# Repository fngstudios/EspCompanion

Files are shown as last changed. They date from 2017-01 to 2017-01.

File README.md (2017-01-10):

# EspCompanion

Esp8266 + Atmega328 dev board.
Discontinued project, with Esp32 its no longer needed.

## Features  

Esp8266 and Atmega328 share the i2c bus, Esp is the master and the mega acts as a i/o
expander, with adc,pwm,serial and other libraries support.
With custom i2c library the Esp can initialize any library on the mega and it will run 
in the background untill the esp request data or sends data.

## Images

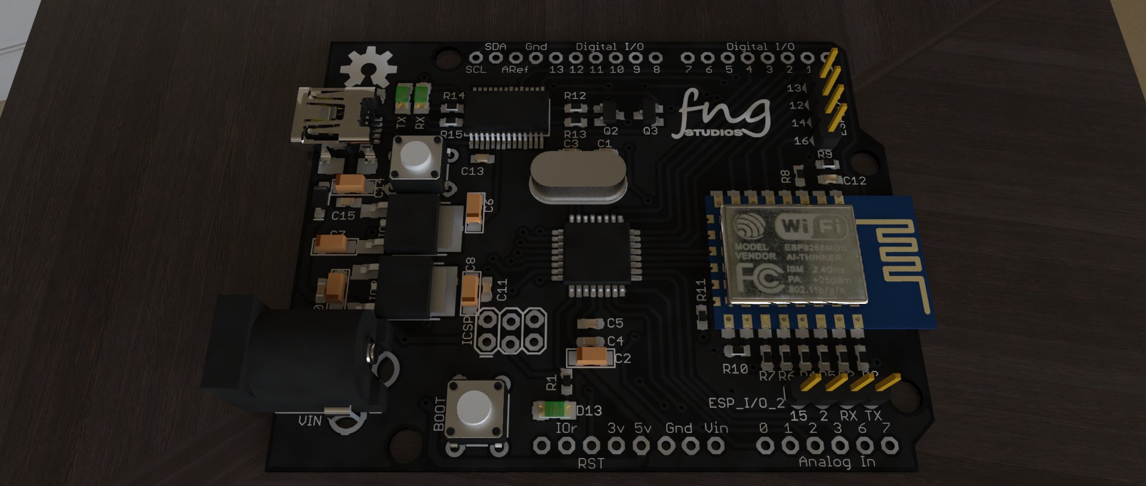
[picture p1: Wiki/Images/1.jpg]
  
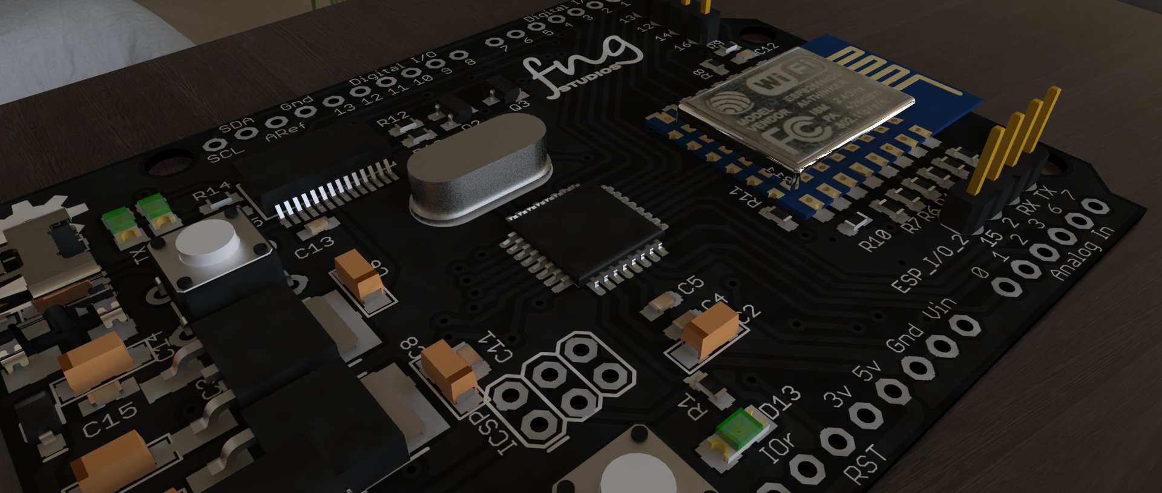
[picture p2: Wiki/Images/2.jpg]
  
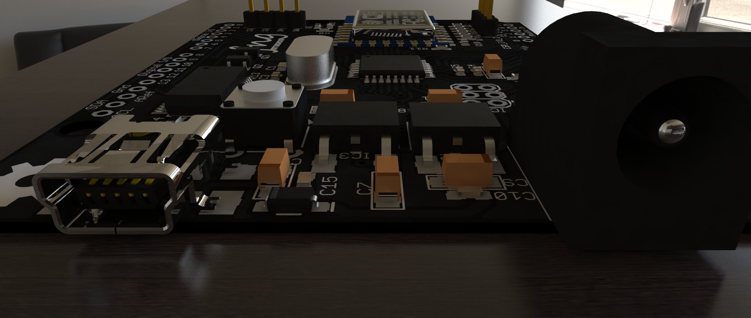
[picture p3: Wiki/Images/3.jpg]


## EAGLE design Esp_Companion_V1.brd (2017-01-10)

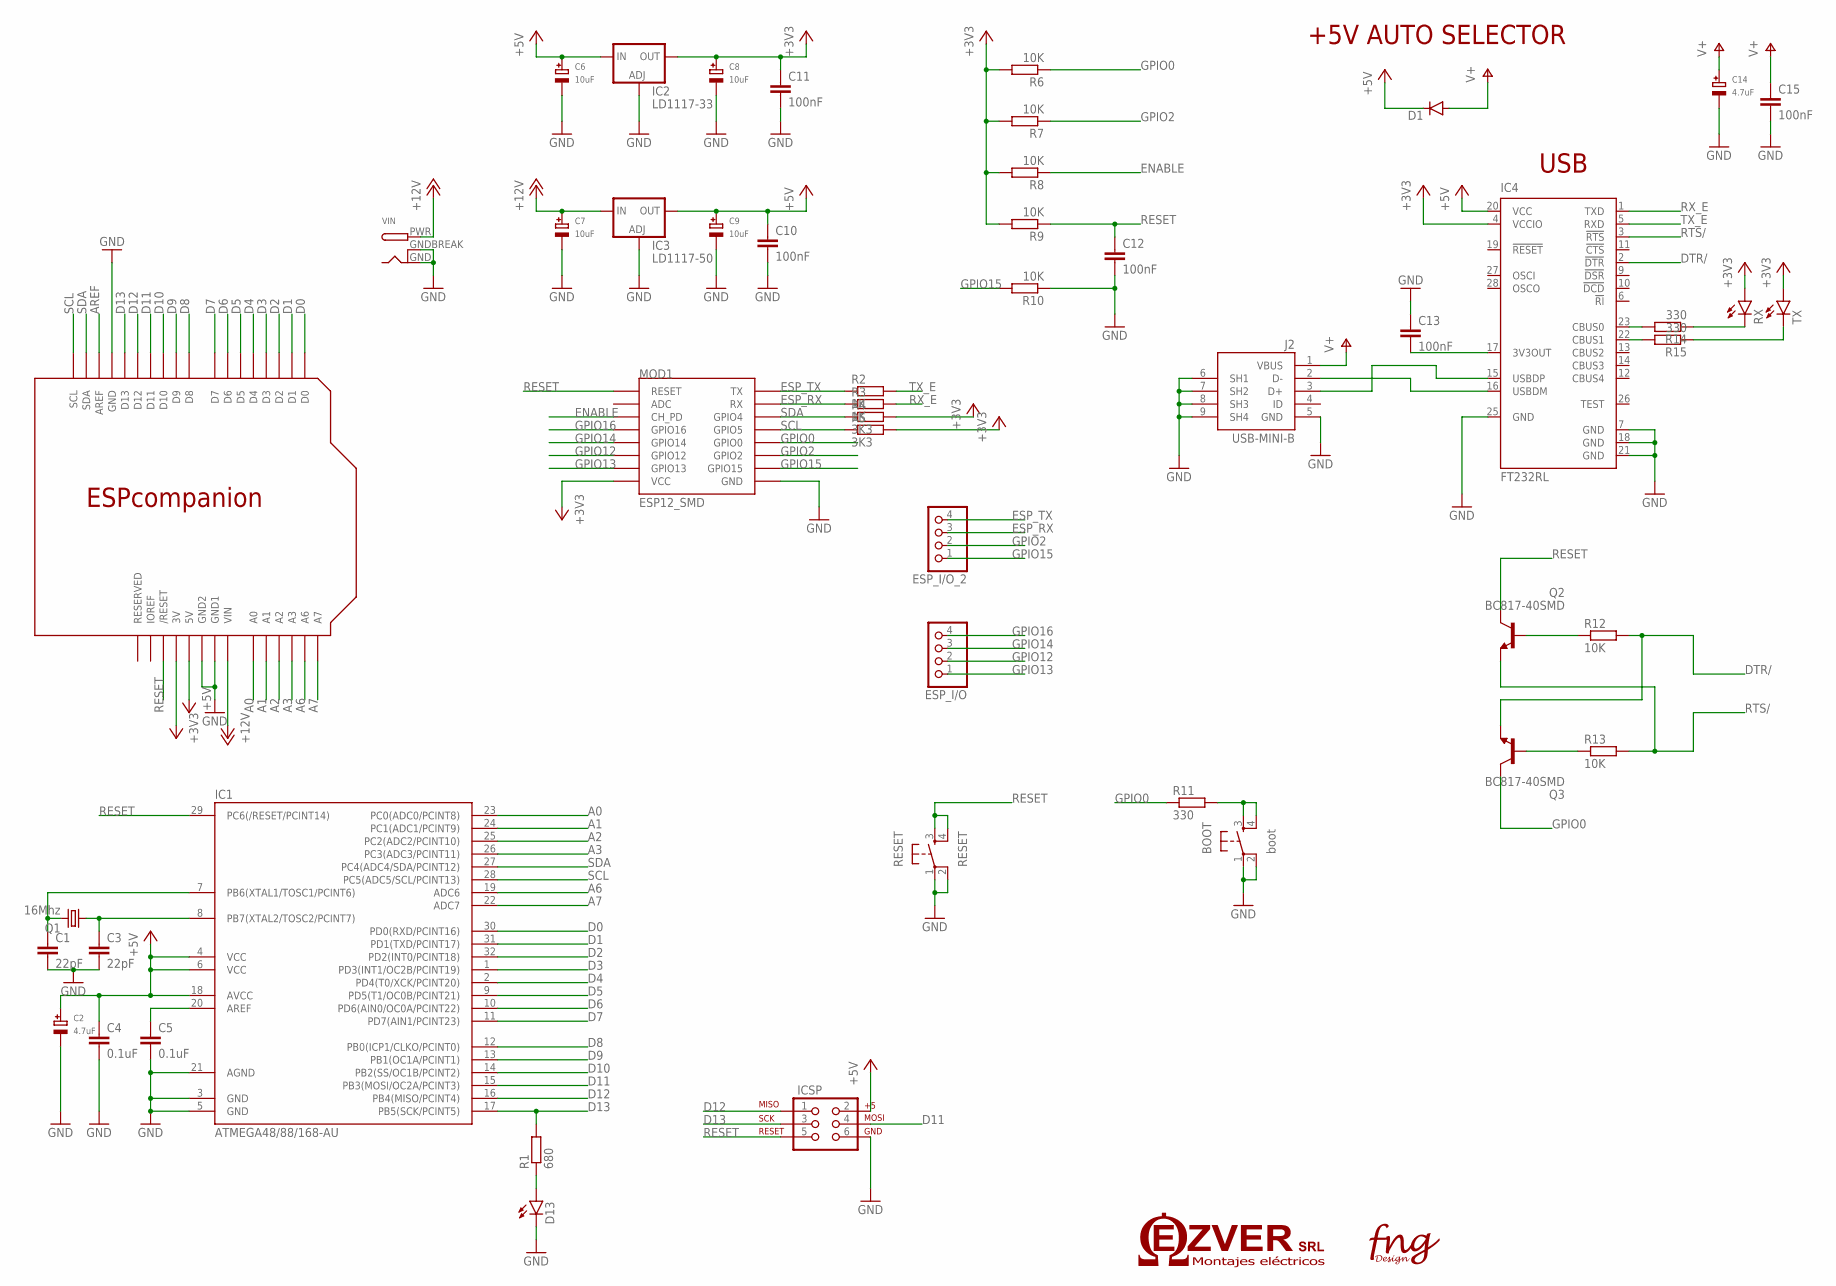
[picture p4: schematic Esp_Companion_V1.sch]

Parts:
BOOT: boot; TACTILE-PTH
C1, C3: 22pF; C0603
C2, C14: 4.7uF; EIA3216-18/A-R
C4, C5: 0.1uF; C0603
C6, C7, C8, C9: 10uF; EIA3216-18/A-R
C10, C11, C12, C13, C15: 100nF; C0603
D1: DIODESMA-ALT; SMA-DIODE_ALT
D13: LED-FKIT-1206; FKIT-LED-1206
ESP_I/O: PINHD-1X4; 1X04
ESP_I/O_2: PINHD-1X4; 1X04
IC1: ATMEGA48/88/168-AU; TQFP32-08
IC2: LD1117-33; DPACK
IC3: LD1117-50; DPACK
IC4: FT232RL; SSOP28
ICSP: AVR_SPI_PRG_62X3_LOCK; 2X3_LOCK
J2: USB-MINI-B
LAY1: ESPCOMPANIONHOLES; ESPCOMPANION_HOLES
MOD1: ESP12_SMD
Q1: 16Mhz; HC49U70
Q2, Q3: BC817-40SMD; SOT23-BEC
R1: 680; R0603
R2, R3: 1K; R0603
R4, R5: 3K3; R0603
R6, R7, R8, R9, R10, R12, R13: 10K; R0603
R11, R14, R15: 330; R0603
RESET: RESET; TACTILE-PTH
RX: LED-FKIT-1206; FKIT-LED-1206
TX: LED-FKIT-1206; FKIT-LED-1206
VIN: DCBARRELPTH; DCJACK_2MM_PTH

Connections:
+3V3: C8.+, C11.1, IC2.4 (OUT), IC4.4 (VCCIO), LAY1.3V, MOD1.P$8 (VCC), R4.2, R5.2, R6.2, R7.2, R8.2, R9.2, RX.A, TX.A
+5V: C2.+, C4.1, C6.+, C9.+, C10.1, D1.C, IC1.4 (VCC), IC1.6 (VCC), IC1.18 (AVCC), IC2.3 (IN), IC3.4 (OUT), IC4.20 (VCC), ICSP.2, LAY1.5V
+12V: C7.+, IC3.3 (IN), LAY1.VIN, VIN.PWR
A0: IC1.23 (PC0(ADC0/PCINT8)), LAY1.A0
A1: IC1.24 (PC1(ADC1/PCINT9)), LAY1.A1
A2: IC1.25 (PC2(ADC2/PCINT10)), LAY1.A2
A3: IC1.26 (PC3(ADC3/PCINT11)), LAY1.A3
A6: IC1.19 (ADC6), LAY1.A6
A7: IC1.22 (ADC7), LAY1.A7
AREF: LAY1.AREF
D0: IC1.30 (PD0(RXD/PCINT16)), LAY1.D0
D1: IC1.31 (PD1(TXD/PCINT17)), LAY1.D1
D2: IC1.32 (PD2(INT0/PCINT18)), LAY1.D2
D3: IC1.1 (PD3(INT1/OC2B/PCINT19)), LAY1.D3
D4: IC1.2 (PD4(T0/XCK/PCINT20)), LAY1.D4
D5: IC1.9 (PD5(T1/OC0B/PCINT21)), LAY1.D5
D6: IC1.10 (PD6(AIN0/OC0A/PCINT22)), LAY1.D6
D7: IC1.11 (PD7(AIN1/PCINT23)), LAY1.D7
D8: IC1.12 (PB0(ICP1/CLKO/PCINT0)), LAY1.D8
D9: IC1.13 (PB1(OC1A/PCINT1)), LAY1.D9
D10: IC1.14 (PB2(SS/OC1B/PCINT2)), LAY1.D10
D11: IC1.15 (PB3(MOSI/OC2A/PCINT3)), ICSP.4, LAY1.D11
D12: IC1.16 (PB4(MISO/PCINT4)), ICSP.1, LAY1.D12
D13: IC1.17 (PB5(SCK/PCINT5)), ICSP.3, LAY1.D13, R1.2
DTR/: IC4.2 (!DTR), Q3.E, R12.2
ENABLE: MOD1.P$3 (CH_PD), R8.1
ESP_RX: ESP_I/O_2.3, MOD1.P$15 (RX), R3.1
ESP_TX: ESP_I/O_2.4, MOD1.P$16 (TX), R2.1
GND: BOOT.1, BOOT.2, C1.2, C2.-, C3.2, C4.2, C5.2, C6.-, C7.-, C8.-, C9.-, C10.2, C11.2, C12.2, C13.1, C14.-, C15.2, D13.C, IC1.3 (GND), IC1.5 (GND), IC1.21 (AGND), IC2.1 (ADJ), IC3.1 (ADJ), IC4.7 (GND), IC4.18 (GND), IC4.21 (GND), IC4.25 (GND), ICSP.6, J2.5 (GND), J2.6 (SH1), J2.7 (SH2), J2.8 (SH3), J2.9 (SH4), LAY1.GND, LAY1.GND1, LAY1.GND2, MOD1.P$9 (GND), R10.1, RESET.1, RESET.2, VIN.GND, VIN.GNDBREAK
GPIO0: MOD1.P$12 (GPIO0), Q3.C, R6.1, R11.1
GPIO2: ESP_I/O_2.2, MOD1.P$11 (GPIO2), R7.1
GPIO12: ESP_I/O.2, MOD1.P$6 (GPIO12)
GPIO13: ESP_I/O.1, MOD1.P$7 (GPIO13)
GPIO14: ESP_I/O.3, MOD1.P$5 (GPIO14)
GPIO15: ESP_I/O_2.1, MOD1.P$10 (GPIO15), R10.2
GPIO16: ESP_I/O.4, MOD1.P$4 (GPIO16)
unnamed: D13.A, R1.1
unnamed: BOOT.3, BOOT.4, R11.2
unnamed: Q2.B, R12.1
unnamed: Q3.B, R13.1
unnamed: C3.1, IC1.8 (PB7(XTAL2/TOSC2/PCINT7)), Q1.1
unnamed: C1.1, IC1.7 (PB6(XTAL1/TOSC1/PCINT6)), Q1.2
unnamed: C5.1, IC1.20 (AREF)
unnamed: C13.2, IC4.17 (3V3OUT)
unnamed: IC4.23 (CBUS0), R14.2
unnamed: IC4.22 (CBUS1), R15.2
unnamed: R15.1, TX.C
unnamed: R14.1, RX.C
unnamed: IC4.16 (USBDM), J2.2 (D-)
unnamed: IC4.15 (USBDP), J2.3 (D+)
RESET: C12.1, IC1.29 (PC6(/RESET/PCINT14)), ICSP.5, LAY1.RESET (/RESET), MOD1.P$1 (RESET), Q2.C, R9.1, RESET.3, RESET.4
RTS/: IC4.3 (!RTS), Q2.E, R13.2
RX_E: IC4.1 (TXD), R3.2
SCL: IC1.28 (PC5(ADC5/SCL/PCINT13)), LAY1.SCL, MOD1.P$14 (GPIO5), R5.1
SDA: IC1.27 (PC4(ADC4/SDA/PCINT12)), LAY1.SDA, MOD1.P$13 (GPIO4), R4.1
TX_E: IC4.5 (RXD), R2.2
V+: C14.+, C15.1, D1.A, J2.1 (VBUS)

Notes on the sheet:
USB
+5V AUTO SELECTOR

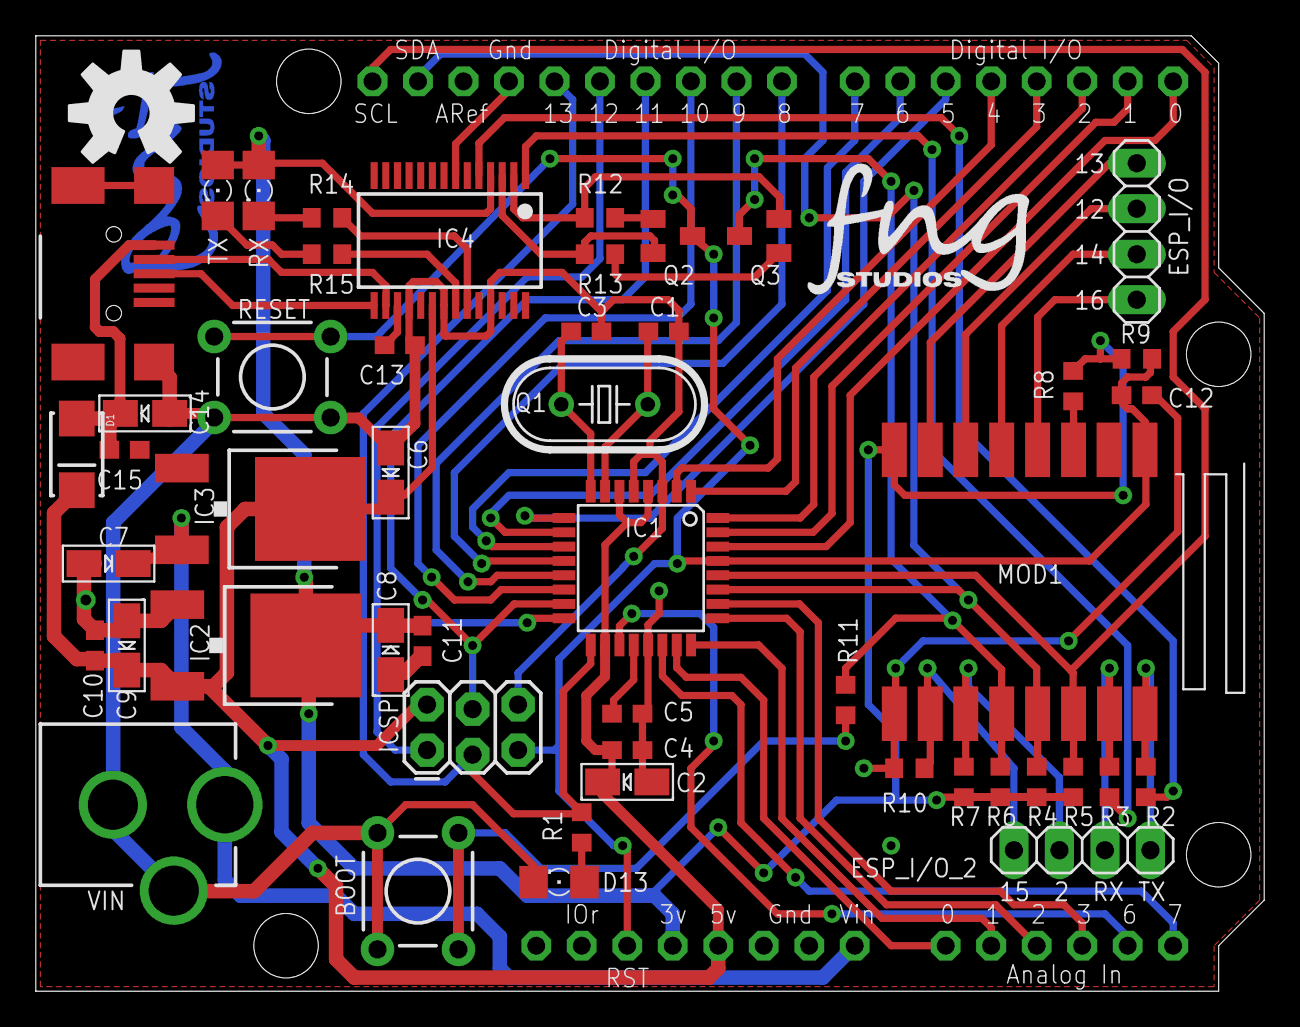
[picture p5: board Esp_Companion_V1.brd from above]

Board: 2 copper layers, 68.6 x 53.3 mm, 53 parts (1 on the bottom side), 56 nets.

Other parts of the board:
U$2: LOGOFNGNAME1
U$3: LOGOFNG
U$4: OSHW-LOGO-L

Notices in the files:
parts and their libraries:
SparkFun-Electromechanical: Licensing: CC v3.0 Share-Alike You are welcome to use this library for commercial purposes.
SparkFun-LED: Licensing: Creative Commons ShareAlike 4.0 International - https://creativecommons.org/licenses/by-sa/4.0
